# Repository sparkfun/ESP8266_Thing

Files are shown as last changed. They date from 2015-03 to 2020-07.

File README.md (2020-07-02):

SparkFun ESP8266 Thing
========================================

SparkFun ESP8266 Thing (https://www.sparkfun.com/products/13231)

[*SparkFun ESP8266 Thing (WRL-13231)*](https://www.sparkfun.com/products/13231)

The [SparkFun ESP8266 Thing](https://www.sparkfun.com/products/13231) is essentially a breakout and development board for the ESP8266 WiFi SoC. Why the name? We lovingly call it the Thing due to it being the perfect foundation for your Internet of Things. Over the past year, the ESP8266 has been a growing star among IoT or WiFi-related projects. It’s an extremely cost-effective WiFi module, that – with a little extra effort – can be programmed just like any microcontroller. The only unfortunate part is: the ESP8266 has mostly only been available in a tiny, modular form, which, with limited I/O and a “unique” pin-out, can be difficult to build a project around. SparkFun’s new development board for the ESP8266 breaks out all of the module’s pins, and comes equipped with a LiPo charger, power supply, and all of the other supporting circuitry it requires.

The SparkFun ESP8266 Thing is a relatively simple board. The pins are broken out to two parallel, breadboard-compatible rows. USB and LiPo connectors at the top of the board provide power – controlled by the nearby ON/OFF switch. And LEDs towards the inside of the board indicate power, charge, and status of the IC. The ESP8266’s maximum voltage is 3.6V, so the Thing has an onboard 3.3V regulator to deliver a safe, consistent voltage to the IC. That means the ESP8266’s I/O pins also run at 3.3V, you’ll need to level shift any 5V signals running into the IC.

Repository Contents
-------------------

* **/Documentation** - Graphical datasheets (.pdf, .svg)
* **/Hardware** - Eagle design files (.brd, .sch)
* **/Production** - Production panel files (.brd)

Documentation
--------------
* **[Hookup Guide](https://learn.sparkfun.com/tutorials/esp8266-thing-hookup-guide)** - Exhaustive hookup guide for the ESP8266 Thing.
* **[SparkFun Fritzing repo](https://github.com/sparkfun/Fritzing_Parts)** - Fritzing diagrams for SparkFun products.
* **[SparkFun 3D Model repo](https://github.com/sparkfun/3D_Models)** - 3D models of SparkFun products. 

Product Versions
----------------
* [DEV-15258](https://www.sparkfun.com/products/15258)- The Thing in a starter kit.
* [DEV-13231](https://www.sparkfun.com/products/13231)- V1.0 release of the Thing.

License Information
-------------------

This product is _**open source**_! 

Please review the LICENSE.md file for license information. 

If you have any questions or concerns on licensing, please contact technical support on our [SparkFun forums](https://forum.sparkfun.com/viewforum.php?f=152).

Please use, reuse, and modify these files as you see fit. Please maintain attribution to SparkFun Electronics and release anything derivative under the same license.

Distributed as-is; no warranty is given.

- Your friends at SparkFun.

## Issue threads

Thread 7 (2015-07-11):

Arduino package does not co-exists with SparkFun PSoC5 Arduino package

blacktigersoftware, 2015-07-11:
If you have the Sparkfun Arduino PSoC5 package, installing the ESP8266_Thing package makes it disappear.  I did a full reinstall of Arduino 1.6.5, carefully following the PSoC5 steps, quiting Arduino after each step, then performed the ESP8266_Thing installation.
The reason why I make this an issue for ESP8266_Thing is that Visual Micro can still see the PSoC5 package (even though Arduino can't), but has never been able to see the ESP8266_Thing package.

santaimpersonator, 2019-12-30:
We have since handed off the installation of ESP8266 Thing into the board manager... to the [ESP8266 core](https://github.com/esp8266/Arduino). Since, we are no longer are managing this process, I will be closing this issue. If you still have issue installing both packages, please file the issue under the appropriate repository.

Closed 2019-12-30.

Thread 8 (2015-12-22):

On the two jumpered pins, the one labeled DTR is incorrect

jeremyabel, 2015-12-22:
Confirmed in the brd file and the physical board, the left-most pin is labeled DTR, but it should be the rightmost pin which is labele DTR.

bboyho, 2019-03-01:
Hi,

The current boards have the correct silkscreen label. I am not sure when this might have occurred but it looks like it was fixed.

Closed 2019-03-01.

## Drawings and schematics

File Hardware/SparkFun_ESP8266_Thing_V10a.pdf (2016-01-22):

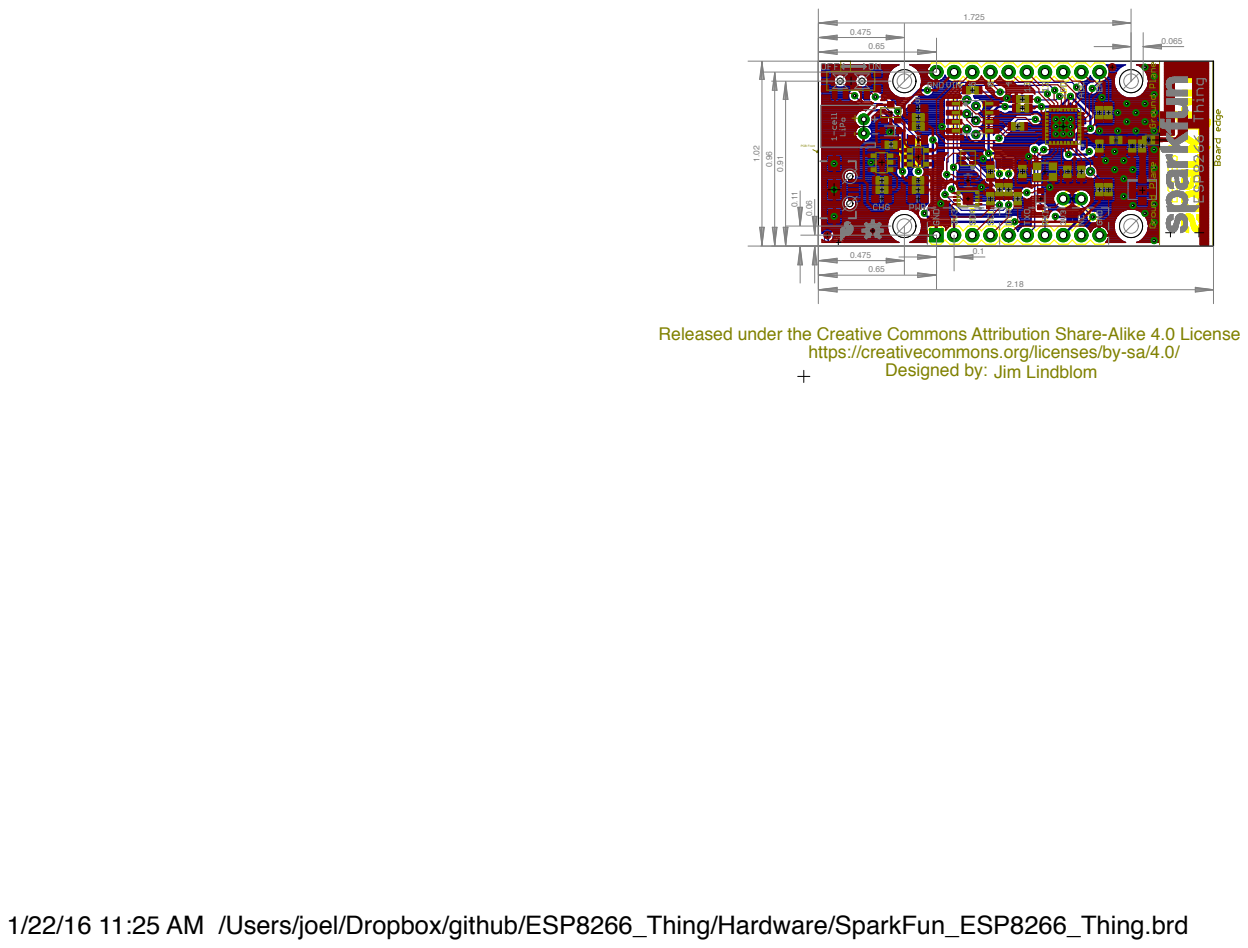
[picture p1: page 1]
Jim Lindblom; Designed by:; PCB Front

Released under the Creative Commons Attribution Share-Alike 4.0 License

https://creativecommons.org/licenses/by-sa/4.0/

1/22/16 11:25 AM /Users/joel/Dropbox/github/ESP8266_Thing/Hardware/SparkFun_ESP8266_Thing.brd

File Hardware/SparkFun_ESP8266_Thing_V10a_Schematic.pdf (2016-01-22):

## VCC Range:

1.7V->3.6V

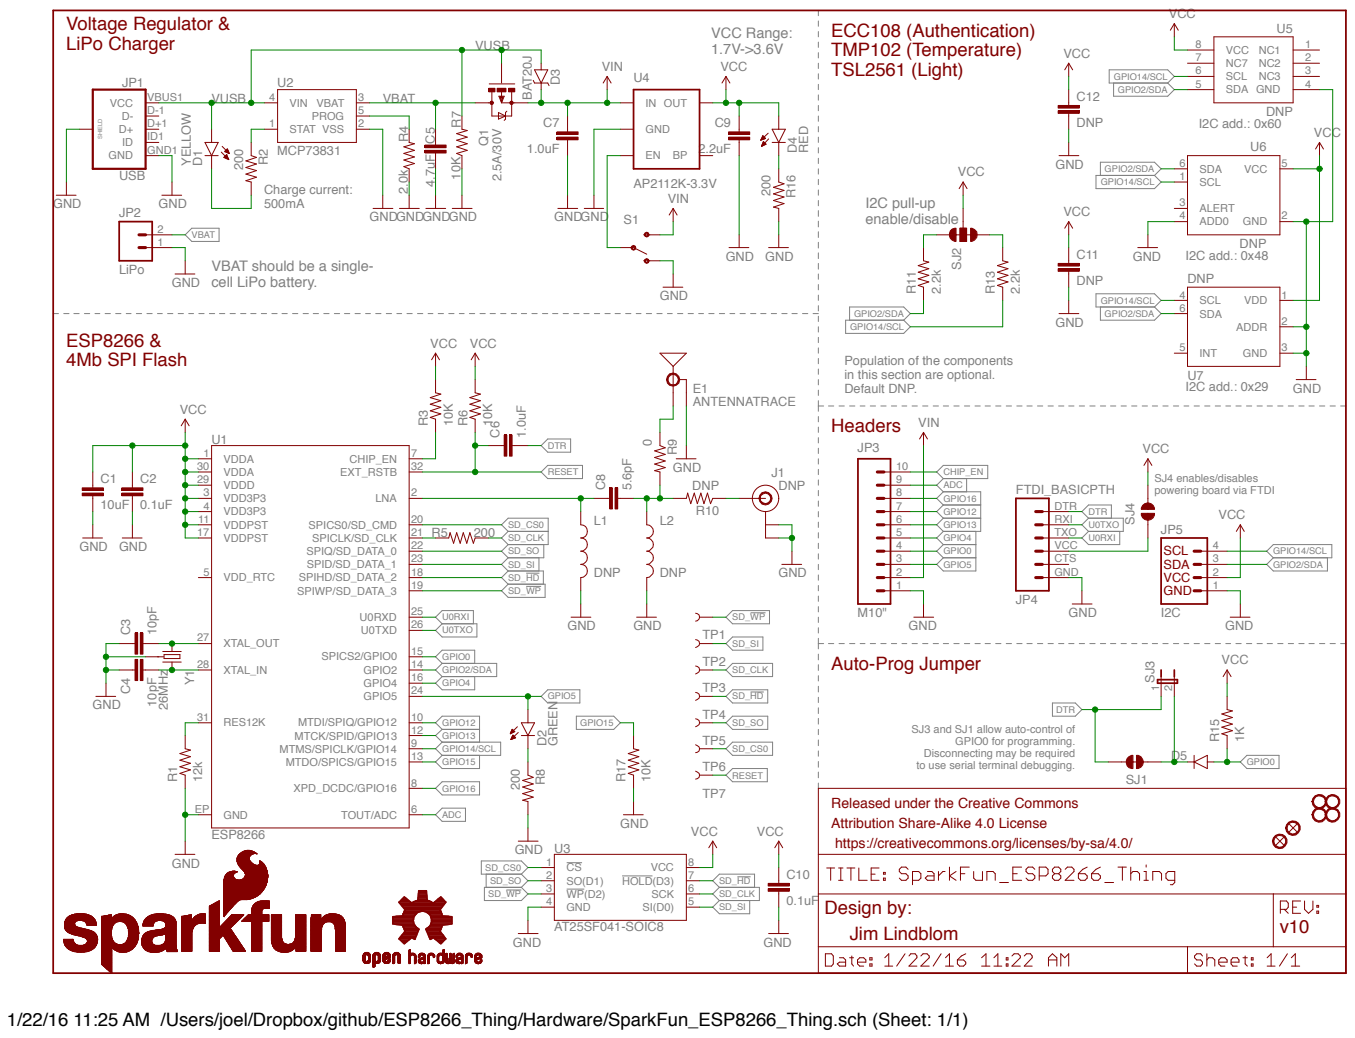
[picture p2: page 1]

VBAT should be a single-
cell LiPo battery.

Population of the components
in this section are optional.
Default DNP.

SJ4 enables/disables
powering board via FTDI

SJ3 and SJ1 allow auto-control of

GPIO0 for programming.
Disconnecting may be required
to use serial terminal debugging.

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

1/22/16 11:25 AM /Users/joel/Dropbox/github/ESP8266_Thing/Hardware/SparkFun_ESP8266_Thing.sch (Sheet: 1/1)

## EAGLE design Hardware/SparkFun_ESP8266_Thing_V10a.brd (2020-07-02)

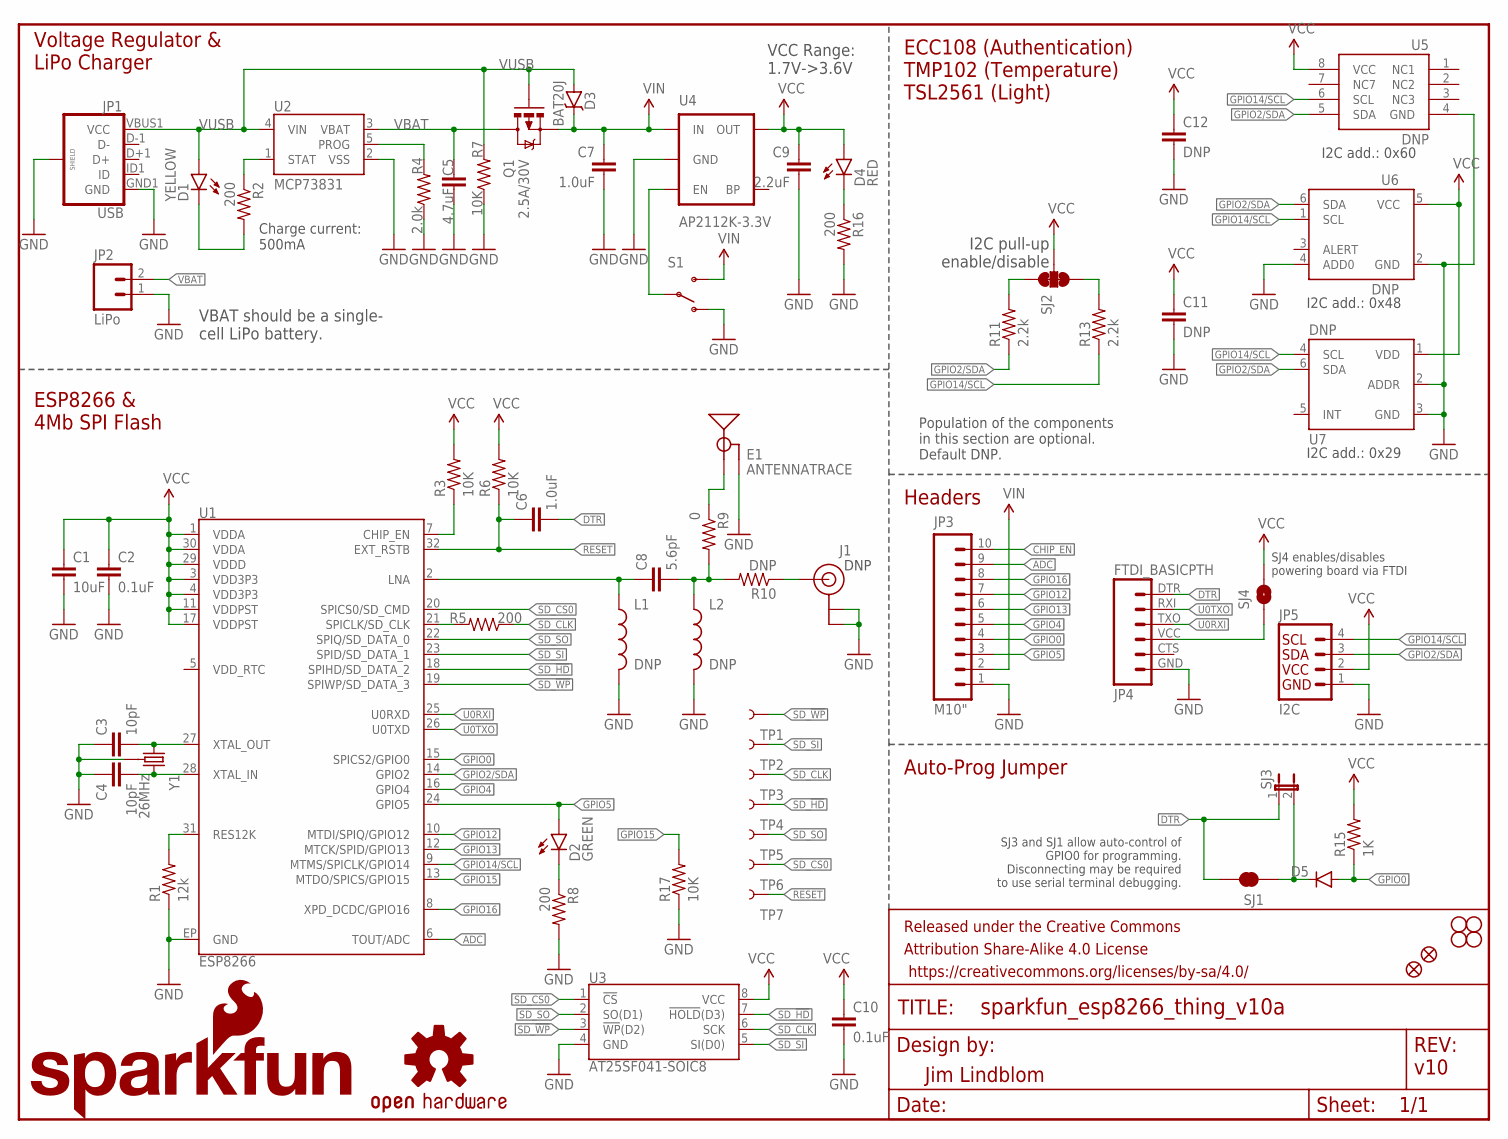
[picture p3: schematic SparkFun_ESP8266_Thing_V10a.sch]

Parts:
C1: 10uF; 0603-CAP
C2, C10: 0.1uF; 0603-CAP
C3, C4: 10pF; 0603-CAP
C5: 4.7uF; 0603-CAP
C6: 1.0uF; 0603-CAP
C7: 1.0uF; 0805
C8: 5.6pF; 0603-CAP
C9: 2.2uF; 0603-CAP
C11, C12: DNP; 0603-CAP
D1: YELLOW; LED-0603
D2: GREEN; LED-0603
D3: BAT20J; SOD-323
D4: RED; LED-0603
D5: DIODEBAS16; SOD-323
E1: ANTENNATRACE; TRACE_ANTENNA_2.4GHZ_25.7MM
FID1, FID2: FIDUCIAL1X2; FIDUCIAL-1X2
FRAME1: FRAME-LETTER; CREATIVE_COMMONS
J1: DNP; U.FL
JP1: USB; USB-B-MICRO-SMD_V03
JP2: LiPo; JST-2-PTH
JP3: M10"; 1X10
JP4: FTDI_BASICPTH; FTDI_BASIC
JP5: I2C; 1X04
L1, L2: DNP; 0603
LOGO1: SFE_LOGO_NAME.2_INCH; SFE_LOGO_NAME_.2
LOGO3: SFE_LOGO_FLAME.1_INCH; SFE_LOGO_FLAME_.1
LOGO4: OSHW-LOGOS; OSHW-LOGO-S
Q1: 2.5A/30V; SOT23-3
R1: 12k; 0603-RES
R2, R5, R8, R16: 200; 0603-RES
R3, R6, R7, R17: 10K; 0603-RES
R4: 2.0k; 0603-RES
R9: 0; 0603
R10: DNP; 0603-RES
R11, R13: 2.2k; 0603-RES
R15: 1K; 0603-RES
S1: SWITCH-SPDT-SMD-A; SWITCH-SPST-SMD-A
SJ1: JUMPER-PAD-2-NC_BY_TRACE; PAD-JUMPER-2-NC_BY_TRACE_YES_SILK
SJ2: JUMPER-PAD-3-NC_BY_TRACE; PAD-JUMPER-3-3OF3_NC_BY_TRACE_YES_SILK_FULL_BOX
SJ3: JUMPER-PTH-2-NC; PTH-JUMPER-NC_BOTTOM_NO_SILK
SJ4: JUMPER-PAD-2-NOYES_SILK; PAD-JUMPER-2-NO_YES_SILK
STANDOFF1, STANDOFF2, STANDOFF3, STANDOFF4: STAND-OFF
TP1, TP2, TP3, TP4, TP5, TP6, TP7: TEST-POINT3X5; PAD.03X.05
U1: ESP8266; QFN32
U2: MCP73831; SOT23-5
U3: AT25SF041-SOIC8; SO08
U4: AP2112K-3.3V; SOT23-5
U5: DNP; UDFN8
U6: DNP; SOT563-2
U7: DNP; FN-6
Y1: 26MHz; CRYSTAL-SMD-3.2X2.5

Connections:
ADC: JP3.9, U1.6 (TOUT/ADC)
ANT: J1.P$3 (SIGNAL), R10.1
CHIP_EN: JP3.10, R3.1, U1.7 (CHIP_EN)
DTR: C6.2, JP4.DTR (1), SJ1.2, SJ3.1
FTDI_VCC: JP4.VCC (4), SJ4.1
GND: C1.2, C2.2, C3.1, C4.1, C5.2, C7.2, C9.2, C10.2, C11.2, C12.2, E1.GND, E1.GND2 (GND), J1.P$1 (GND), J1.P$2 (GND), JP1.GND1 (GND), JP1.SHIELD1 (SHIELD), JP1.SHIELD2 (SHIELD), JP1.SHIELD3 (SHIELD), JP2.1, JP3.1, JP4.GND (6), JP5.1, L1.2, L2.2, R1.1, R4.1, R7.1, R8.2, R16.2, R17.1, S1.1 (O), U1.EP (GND), U2.2 (VSS), U3.4 (GND), U4.2 (GND), U5.4 (GND), U6.2 (GND), U6.4 (ADD0), U7.2 (ADDR), U7.3 (GND), Y1.2 (GND), Y1.4 (GND)
GPIO0: D5.A, JP3.4, R15.1, U1.15 (SPICS2/GPIO0)
GPIO2/SDA: JP5.3, R11.1, U1.14 (GPIO2), U5.5 (SDA), U6.6 (SDA), U7.6 (SDA)
GPIO4: JP3.5, U1.16 (GPIO4)
GPIO5: D2.A, JP3.3, U1.24 (GPIO5)
GPIO12: JP3.7, U1.10 (MTDI/SPIQ/GPIO12)
GPIO13: JP3.6, U1.12 (MTCK/SPID/GPIO13)
GPIO14/SCL: JP5.4, R13.1, U1.9 (MTMS/SPICLK/GPIO14), U5.6 (SCL), U6.1 (SCL), U7.4 (SCL)
GPIO15: R17.2, U1.13 (MTDO/SPICS/GPIO15)
GPIO16: JP3.8, U1.8 (XPD_DCDC/GPIO16)
LNA: C8.1, L1.1, U1.2 (LNA)
unnamed: R1.2, U1.31 (RES12K)
unnamed: C4.2, U1.28 (XTAL_IN), Y1.3 (2)
unnamed: C3.2, U1.27 (XTAL_OUT), Y1.1
unnamed: D4.C, R16.1
unnamed: C8.2, L2.1, R9.2, R10.2
unnamed: R5.2, U1.21 (SPICLK/SD_CLK)
unnamed: D5.C, SJ1.1, SJ3.2
unnamed: R11.2, SJ2.1
unnamed: R13.2, SJ2.3
unnamed: S1.2, U4.3 (EN)
unnamed: R4.2, U2.5 (PROG)
unnamed: D2.C, R8.1
unnamed: D1.C, R2.2
unnamed: R2.1, U2.1 (STAT)
RESET: C6.1, R6.1, TP7.P$1, U1.32 (EXT_RSTB)
SD_!HD!: TP4.P$1, U1.18 (SPIHD/SD_DATA_2), U3.7 (!HOLD!(D3))
SD_!WP!: TP1.P$1, U1.19 (SPIWP/SD_DATA_3), U3.3 (!WP!(D2))
SD_CLK: R5.1, TP3.P$1, U3.6 (SCK)
SD_CS0: TP6.P$1, U1.20 (SPICS0/SD_CMD), U3.1 (!CS!)
SD_SI: TP2.P$1, U1.23 (SPID/SD_DATA_1), U3.5 (SI(D0))
SD_SO: TP5.P$1, U1.22 (SPIQ/SD_DATA_0), U3.2 (SO(D1))
TRACE_ANT: E1.ANT (SIGNAL), R9.1
U0RXI: JP4.TXO (3), U1.25 (U0RXD)
U0TXO: JP4.RXI (2), U1.26 (U0TXD)
VBAT: C5.1, JP2.2, Q1.3 (D), U2.3 (VBAT)
VCC: C1.1, C2.1, C9.1, C10.1, C11.1, C12.1, D4.A, JP5.2, R3.2, R6.2, R15.2, SJ2.2, SJ4.2, U1.1 (VDDA), U1.3 (VDD3P3), U1.4 (VDD3P3), U1.11 (VDDPST), U1.17 (VDDPST), U1.29 (VDDD), U1.30 (VDDA), U3.8 (VCC), U4.5 (OUT), U5.8 (VCC), U6.5 (VCC), U7.1 (VDD)
VIN: C7.1, D3.C, JP3.2, Q1.2 (S), S1.3 (S), U4.1 (IN)
VUSB: D1.A, D3.A, JP1.VBUS1 (VCC), Q1.1 (G), R7.2, U2.4 (VIN)

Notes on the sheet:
Jim Lindblom
ECC108 (Authentication) TMP102 (Temperature) TSL2561 (Light)
Voltage Regulator & LiPo Charger
ESP8266 & 4Mb SPI Flash
Headers
Auto-Prog Jumper
v10
VCC Range: 1.7V->3.6V
VBAT should be a single- cell LiPo battery.
I2C pull-up enable/disable
SJ4 enables/disables powering board via FTDI
SJ3 and SJ1 allow auto-control of GPIO0 for programming. Disconnecting may be required to use serial terminal debugging.
I2C add.: 0x48
I2C add.: 0x60
I2C add.: 0x29
Population of the components in this section are optional. Default DNP.
Charge current: 500mA
DNP

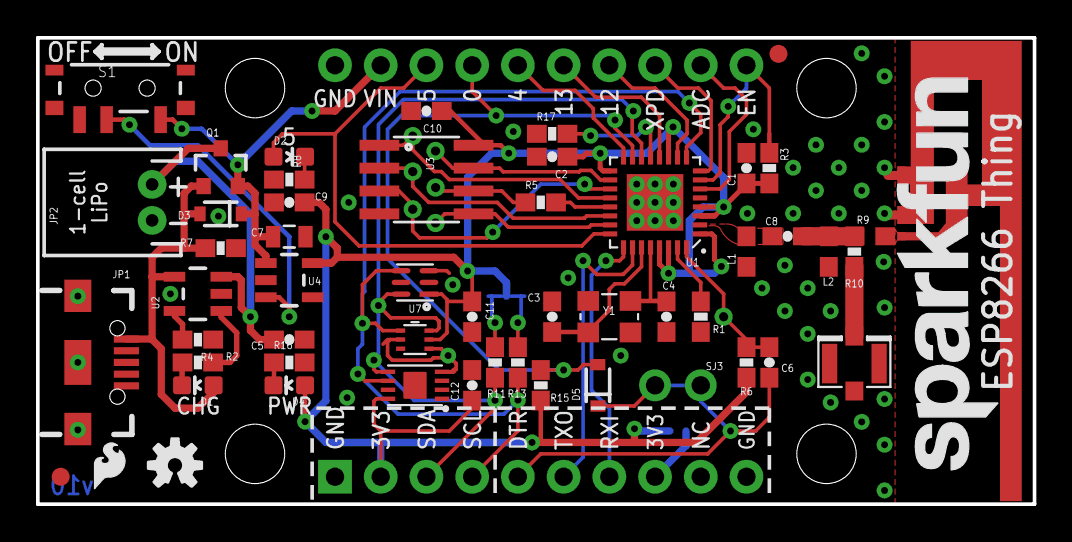
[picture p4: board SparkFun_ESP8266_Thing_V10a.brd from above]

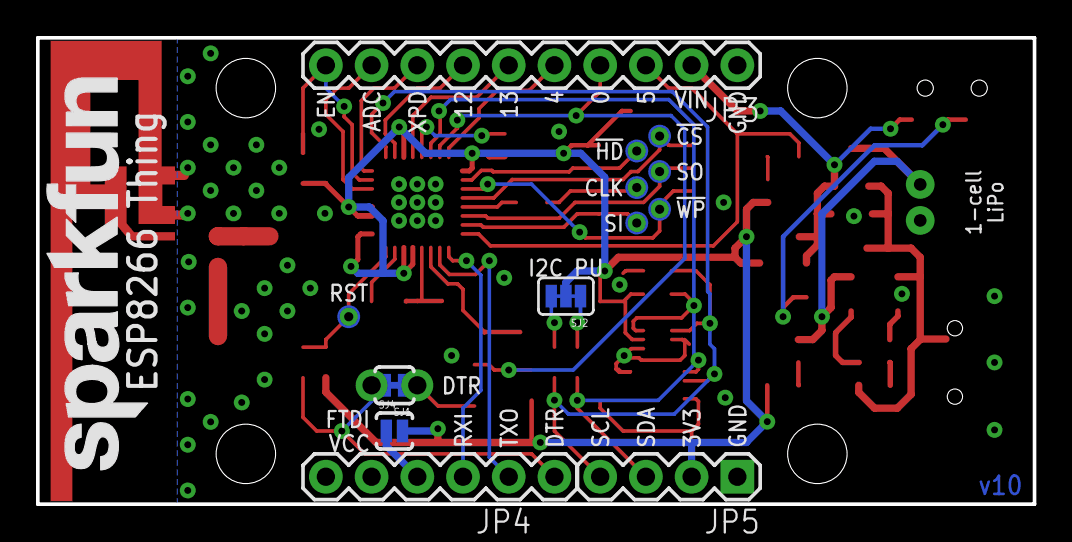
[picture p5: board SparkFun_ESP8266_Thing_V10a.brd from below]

Board: 2 copper layers, 55.4 x 25.9 mm, 73 parts (14 on the bottom side), 44 nets.

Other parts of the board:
LOGO5: SFE_LOGO_NAME.2_INCH; SFE_LOGO_NAME_.2

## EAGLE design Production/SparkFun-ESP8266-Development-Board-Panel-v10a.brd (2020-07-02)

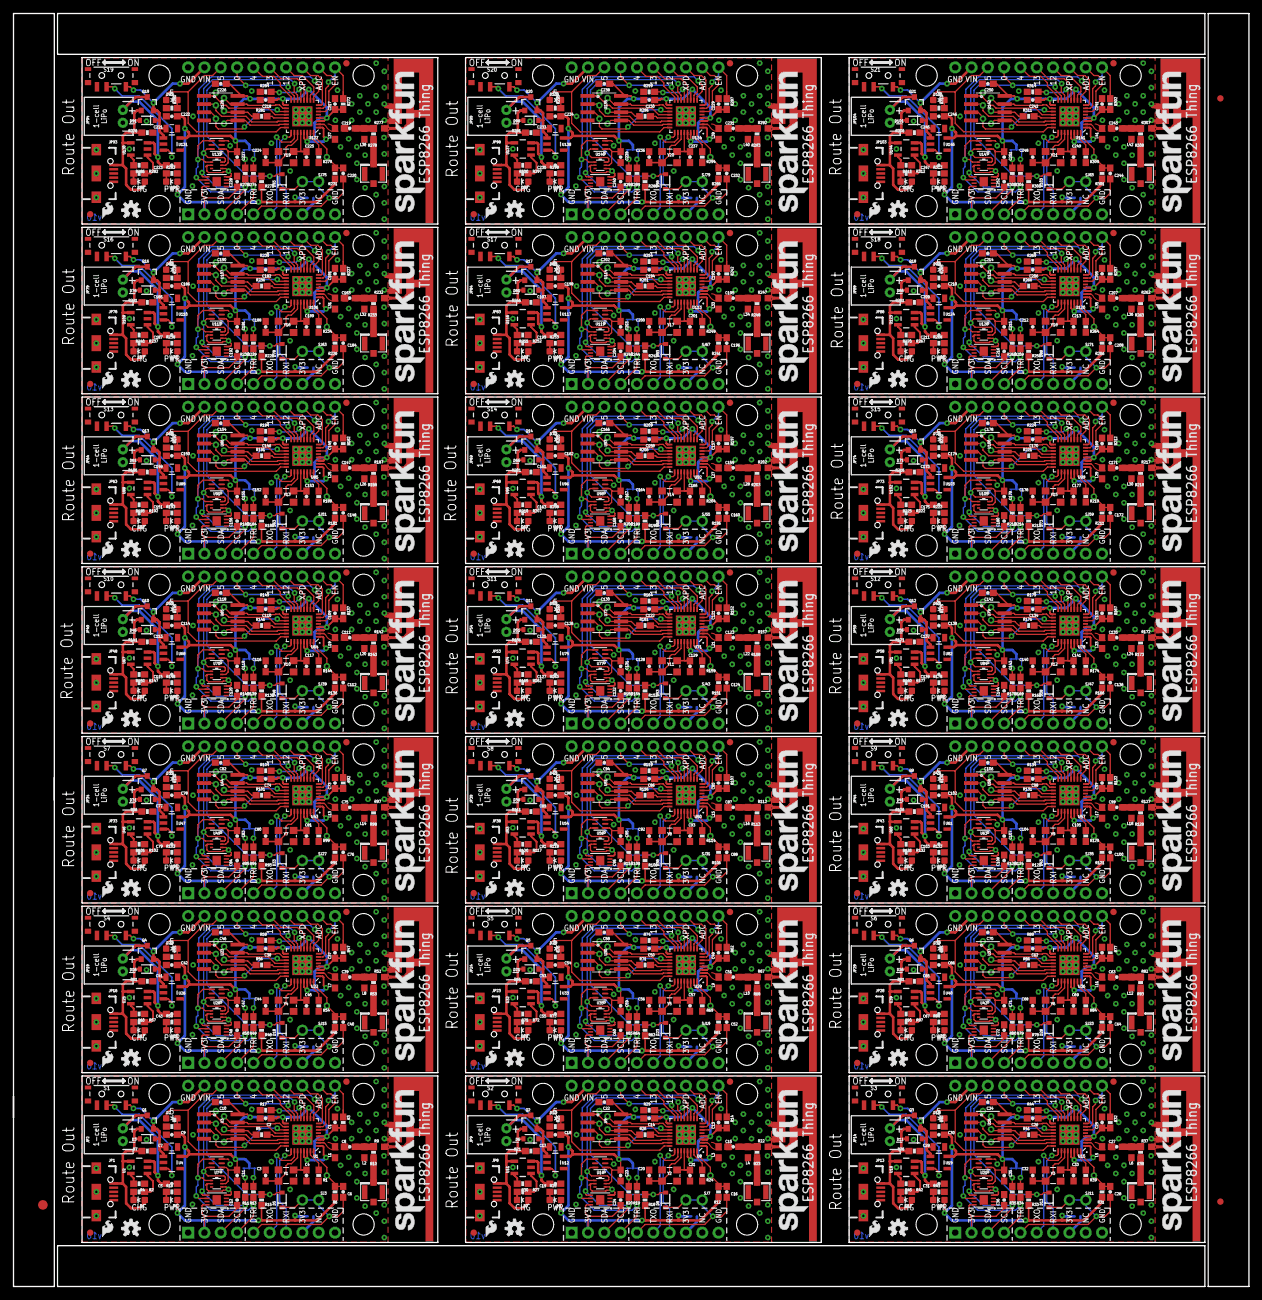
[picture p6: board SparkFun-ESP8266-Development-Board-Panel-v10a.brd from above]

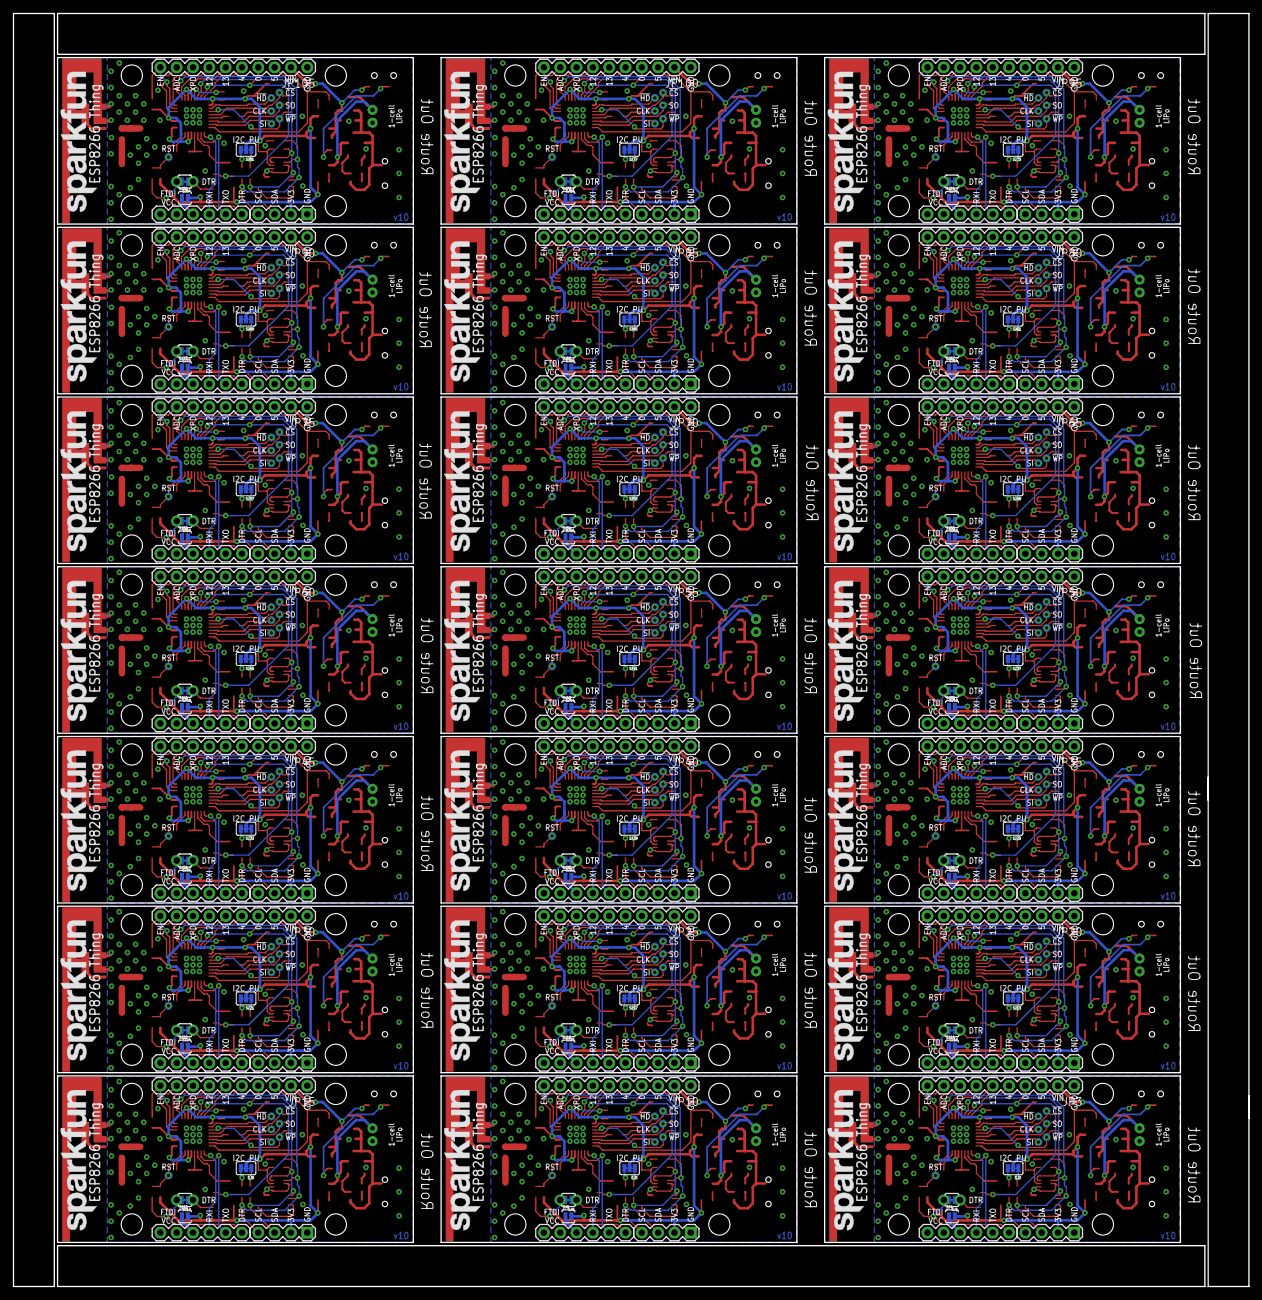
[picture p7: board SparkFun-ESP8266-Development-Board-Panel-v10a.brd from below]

Board: 2 copper layers, 192.3 x 198.1 mm, 1515 parts (294 on the bottom side), 924 nets.

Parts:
C1, C13, C25, C37, C49, C61, C73, C85, C97, C109, C121, C133, C145, C157, C169, C181, C193, C205, C217, C229, C241: 10uF; 0603-CAP
C2, C10, C11, C12, C14, C22, C23, C24, C26, C34, C35, C36, C38, C46, C47, C48, C50, C58, C59, C60, C62, C70, C71, C72, C74, C82, C83, C84, C86, C94, C95, C96, C98, C106, C107, C108, C110, C118, C119, C120, C122, C130, C131, C132, C134, C142, C143, C144, C146, C154, C155, C156, C158, C166, C167, C168, C170, C178, C179, C180, C182, C190, C191, C192, C194, C202, C203, C204, C206, C214, C215, C216, C218, C226, C227, C228, C230, C238, C239, C240, C242, C250, C251, C252: 0.1uF; 0603-CAP
C3, C4, C20, C21, C32, C33, C44, C45, C56, C57, C68, C69, C80, C81, C92, C93, C104, C105, C116, C117, C128, C129, C140, C141, C152, C153, C164, C165, C176, C177, C188, C189, C200, C201, C212, C213, C224, C225, C236, C237, C248, C249: 10pF; 0603-CAP
C5, C19, C31, C43, C55, C67, C79, C91, C103, C115, C127, C139, C151, C163, C175, C187, C199, C211, C223, C235, C247: 4.7uF; 0603-CAP
C6, C16, C28, C40, C52, C64, C76, C88, C100, C112, C124, C136, C148, C160, C172, C184, C196, C208, C220, C232, C244: 1.0uF; 0603-CAP
C7, C17, C29, C41, C53, C65, C77, C89, C101, C113, C125, C137, C149, C161, C173, C185, C197, C209, C221, C233, C245: 1.0uF; 0805
C8, C15, C27, C39, C51, C63, C75, C87, C99, C111, C123, C135, C147, C159, C171, C183, C195, C207, C219, C231, C243: 5.6pF; 0603-CAP
C9, C18, C30, C42, C54, C66, C78, C90, C102, C114, C126, C138, C150, C162, C174, C186, C198, C210, C222, C234, C246: 2.2uF; 0603-CAP
D1, D7, D12, D17, D22, D27, D32, D37, D42, D47, D52, D57, D62, D67, D72, D77, D82, D87, D92, D97, D102: YELLOW; LED-0603
D2, D10, D15, D20, D25, D30, D35, D40, D45, D50, D55, D60, D65, D70, D75, D80, D85, D90, D95, D100, D105: GREEN; LED-0603
D3, D6, D11, D16, D21, D26, D31, D36, D41, D46, D51, D56, D61, D66, D71, D76, D81, D86, D91, D96, D101: BAT20J; SOD-323
D4, D9, D14, D19, D24, D29, D34, D39, D44, D49, D54, D59, D64, D69, D74, D79, D84, D89, D94, D99, D104: RED; LED-0603
D5, D8, D13, D18, D23, D28, D33, D38, D43, D48, D53, D58, D63, D68, D73, D78, D83, D88, D93, D98, D103: SOD-323
E1, E2, E3, E4, E5, E6, E7, E8, E9, E10, E11, E12, E13, E14, E15, E16, E17, E18, E19, E20, E21: ANTENNATRACE; TRACE_ANTENNA_2.4GHZ_25.7MM
E$1: FIDUCIAL-1.5X3
E$5, E$6: FIDUCIAL-1X2
FID1, FID2, FID3, FID4, FID5, FID6, FID7, FID8, FID9, FID10, FID11, FID12, FID13, FID14, FID15, FID16, FID17, FID18, FID19, FID20, FID21, FID22, FID23, FID24, FID25, FID26, FID27, FID28, FID29, FID30, FID31, FID32, FID33, FID34, FID35, FID36, FID37, FID38, FID39, FID40, FID41, FID42: FIDUCIAL1X2; FIDUCIAL-1X2
J1, J2, J3, J4, J5, J6, J7, J8, J9, J10, J11, J12, J13, J14, J15, J16, J17, J18, J19, J20, J21: DNP; U.FL
JP1, JP8, JP13, JP18, JP23, JP28, JP33, JP38, JP43, JP48, JP53, JP58, JP63, JP68, JP73, JP78, JP83, JP88, JP93, JP98, JP103: USB; USB-B-MICRO-SMD_V03
JP2, JP9, JP14, JP19, JP24, JP29, JP34, JP39, JP44, JP49, JP54, JP59, JP64, JP69, JP74, JP79, JP84, JP89, JP94, JP99, JP104: LiPo; JST-2-PTH
JP3, JP10, JP15, JP20, JP25, JP30, JP35, JP40, JP45, JP50, JP55, JP60, JP65, JP70, JP75, JP80, JP85, JP90, JP95, JP100, JP105: M10"; 1X10
JP4, JP6, JP11, JP16, JP21, JP26, JP31, JP36, JP41, JP46, JP51, JP56, JP61, JP66, JP71, JP76, JP81, JP86, JP91, JP96, JP101: FTDI_BASICPTH; FTDI_BASIC
JP5, JP7, JP12, JP17, JP22, JP27, JP32, JP37, JP42, JP47, JP52, JP57, JP62, JP67, JP72, JP77, JP82, JP87, JP92, JP97, JP102: I2C; 1X04
L1, L2, L3, L4, L5, L6, L7, L8, L9, L10, L11, L12, L13, L14, L15, L16, L17, L18, L19, L20, L21, L22, L23, L24, L25, L26, L27, L28, L29, L30, L31, L32, L33, L34, L35, L36, L37, L38, L39, L40, L41, L42: DNP; 0603
LOGO1, LOGO2, LOGO5, LOGO8, LOGO9, LOGO12, LOGO13, LOGO16, LOGO17, LOGO20, LOGO21, LOGO24, LOGO25, LOGO28, LOGO29, LOGO32, LOGO33, LOGO36, LOGO37, LOGO40, LOGO41, LOGO44, LOGO45, LOGO48, LOGO49, LOGO52, LOGO53, LOGO56, LOGO57, LOGO60, LOGO61, LOGO64, LOGO65, LOGO68, LOGO69, LOGO72, LOGO73, LOGO76, LOGO77, LOGO80, LOGO81, LOGO84: SFE_LOGO_NAME.2_INCH; SFE_LOGO_NAME_.2
LOGO3, LOGO6, LOGO10, LOGO14, LOGO18, LOGO22, LOGO26, LOGO30, LOGO34, LOGO38, LOGO42, LOGO46, LOGO50, LOGO54, LOGO58, LOGO62, LOGO66, LOGO70, LOGO74, LOGO78, LOGO82: SFE_LOGO_FLAME.1_INCH; SFE_LOGO_FLAME_.1
LOGO4, LOGO7, LOGO11, LOGO15, LOGO19, LOGO23, LOGO27, LOGO31, LOGO35, LOGO39, LOGO43, LOGO47, LOGO51, LOGO55, LOGO59, LOGO63, LOGO67, LOGO71, LOGO75, LOGO79, LOGO83: OSHW-LOGOS; OSHW-LOGO-S
Q1, Q2, Q3, Q4, Q5, Q6, Q7, Q8, Q9, Q10, Q11, Q12, Q13, Q14, Q15, Q16, Q17, Q18, Q19, Q20, Q21: 2.5A/30V; SOT23-3
R1, R24, R39, R54, R69, R84, R99, R114, R129, R144, R159, R174, R189, R204, R219, R234, R249, R264, R279, R294, R309: 12k; 0603-RES
R2, R5, R8, R16, R25, R26, R27, R28, R40, R41, R42, R43, R55, R56, R57, R58, R70, R71, R72, R73, R85, R86, R87, R88, R100, R101, R102, R103, R115, R116, R117, R118, R130, R131, R132, R133, R145, R146, R147, R148, R160, R161, R162, R163, R175, R176, R177, R178, R190, R191, R192, R193, R205, R206, R207, R208, R220, R221, R222, R223, R235, R236, R237, R238, R250, R251, R252, R253, R265, R266, R267, R268, R280, R281, R282, R283, R295, R296, R297, R298, R310, R311, R312, R313: 200; 0603-RES
R3, R6, R7, R12, R14, R17, R21, R29, R31, R32, R36, R44, R46, R47, R51, R59, R61, R62, R66, R74, R76, R77, R81, R89, R91, R92, R96, R104, R106, R107, R111, R119, R121, R122, R126, R134, R136, R137, R141, R149, R151, R152, R156, R164, R166, R167, R171, R179, R181, R182, R186, R194, R196, R197, R201, R209, R211, R212, R216, R224, R226, R227, R231, R239, R241, R242, R246, R254, R256, R257, R261, R269, R271, R272, R276, R284, R286, R287, R291, R299, R301, R302, R306, R314: 10K; 0603-RES
R4, R30, R45, R60, R75, R90, R105, R120, R135, R150, R165, R180, R195, R210, R225, R240, R255, R270, R285, R300, R315: 2.0k; 0603-RES
R9, R22, R37, R52, R67, R82, R97, R112, R127, R142, R157, R172, R187, R202, R217, R232, R247, R262, R277, R292, R307: 0; 0603
R10, R23, R38, R53, R68, R83, R98, R113, R128, R143, R158, R173, R188, R203, R218, R233, R248, R263, R278, R293, R308: DNP; 0603-RES
R11, R13, R19, R20, R34, R35, R49, R50, R64, R65, R79, R80, R94, R95, R109, R110, R124, R125, R139, R140, R154, R155, R169, R170, R184, R185, R199, R200, R214, R215, R229, R230, R244, R245, R259, R260, R274, R275, R289, R290, R304, R305: 2.2k; 0603-RES
R15, R18, R33, R48, R63, R78, R93, R108, R123, R138, R153, R168, R183, R198, R213, R228, R243, R258, R273, R288, R303: 1K; 0603-RES
S1, S2, S3, S4, S5, S6, S7, S8, S9, S10, S11, S12, S13, S14, S15, S16, S17, S18, S19, S20, S21: SWITCH-SPST-SMD-A
SJ1, SJ8, SJ12, SJ16, SJ20, SJ24, SJ28, SJ32, SJ36, SJ40, SJ44, SJ48, SJ52, SJ56, SJ60, SJ64, SJ68, SJ72, SJ76, SJ80, SJ84: PAD-JUMPER-2-NC_BY_TRACE_YES_SILK
SJ2, SJ5, SJ9, SJ13, SJ17, SJ21, SJ25, SJ29, SJ33, SJ37, SJ41, SJ45, SJ49, SJ53, SJ57, SJ61, SJ65, SJ69, SJ73, SJ77, SJ81: PAD-JUMPER-3-3OF3_NC_BY_TRACE_YES_SILK_FULL_BOX
SJ3, SJ7, SJ11, SJ15, SJ19, SJ23, SJ27, SJ31, SJ35, SJ39, SJ43, SJ47, SJ51, SJ55, SJ59, SJ63, SJ67, SJ71, SJ75, SJ79, SJ83: PTH-JUMPER-NC_BOTTOM_NO_SILK
SJ4, SJ6, SJ10, SJ14, SJ18, SJ22, SJ26, SJ30, SJ34, SJ38, SJ42, SJ46, SJ50, SJ54, SJ58, SJ62, SJ66, SJ70, SJ74, SJ78, SJ82: PAD-JUMPER-2-NO_YES_SILK
STANDOFF1, STANDOFF2, STANDOFF3, STANDOFF4, STANDOFF5, STANDOFF6, STANDOFF7, STANDOFF8, STANDOFF9, STANDOFF10, STANDOFF11, STANDOFF12, STANDOFF13, STANDOFF14, STANDOFF15, STANDOFF16, STANDOFF17, STANDOFF18, STANDOFF19, STANDOFF20, STANDOFF21, STANDOFF22, STANDOFF23, STANDOFF24, STANDOFF25, STANDOFF26, STANDOFF27, STANDOFF28, STANDOFF29, STANDOFF30, STANDOFF31, STANDOFF32, STANDOFF33, STANDOFF34, STANDOFF35, STANDOFF36, STANDOFF37, STANDOFF38, STANDOFF39, STANDOFF40, STANDOFF41, STANDOFF42, STANDOFF43, STANDOFF44, STANDOFF45, STANDOFF46, STANDOFF47, STANDOFF48, STANDOFF49, STANDOFF50, STANDOFF51, STANDOFF52, STANDOFF53, STANDOFF54, STANDOFF55, STANDOFF56, STANDOFF57, STANDOFF58, STANDOFF59, STANDOFF60, STANDOFF61, STANDOFF62, STANDOFF63, STANDOFF64, STANDOFF65, STANDOFF66, STANDOFF67, STANDOFF68, STANDOFF69, STANDOFF70, STANDOFF71, STANDOFF72, STANDOFF73, STANDOFF74, STANDOFF75, STANDOFF76, STANDOFF77, STANDOFF78, STANDOFF79, STANDOFF80, STANDOFF81, STANDOFF82, STANDOFF83, STANDOFF84: STAND-OFF
TP1, TP2, TP3, TP4, TP5, TP6, TP7, TP8, TP9, TP10, TP11, TP12, TP13, TP14, TP15, TP16, TP17, TP18, TP19, TP20, TP21, TP22, TP23, TP24, TP25, TP26, TP27, TP28, TP29, TP30, TP31, TP32, TP33, TP34, TP35, TP36, TP37, TP38, TP39, TP40, TP41, TP42, TP43, TP44, TP45, TP46, TP47, TP48, TP49, TP50, TP51, TP52, TP53, TP54, TP55, TP56, TP57, TP58, TP59, TP60, TP61, TP62, TP63, TP64, TP65, TP66, TP67, TP68, TP69, TP70, TP71, TP72, TP73, TP74, TP75, TP76, TP77, TP78, TP79, TP80, TP81, TP82, TP83, TP84, TP85, TP86, TP87, TP88, TP89, TP90, TP91, TP92, TP93, TP94, TP95, TP96, TP97, TP98, TP99, TP100, TP101, TP102, TP103, TP104, TP105, TP106, TP107, TP108, TP109, TP110, TP111, TP112, TP113, TP114, TP115, TP116, TP117, TP118, TP119, TP120, TP121, TP122, TP123, TP124, TP125, TP126, TP127, TP128, TP129, TP130, TP131, TP132, TP133, TP134, TP135, TP136, TP137, TP138, TP139, TP140, TP141, TP142, TP143, TP144, TP145, TP146, TP147: PAD.03X.05
U1, U8, U15, U22, U29, U36, U43, U50, U57, U64, U71, U78, U85, U92, U99, U106, U113, U120, U127, U134, U141: ESP8266; QFN32
U2, U11, U18, U25, U32, U39, U46, U53, U60, U67, U74, U81, U88, U95, U102, U109, U116, U123, U130, U137, U144: MCP73831; SOT23-5
U3, U9, U16, U23, U30, U37, U44, U51, U58, U65, U72, U79, U86, U93, U100, U107, U114, U121, U128, U135, U142: AT25SF041-SOIC8; SO08
U4, U12, U19, U26, U33, U40, U47, U54, U61, U68, U75, U82, U89, U96, U103, U110, U117, U124, U131, U138, U145: AP2112K-3.3V; SOT23-5
U5, U10, U17, U24, U31, U38, U45, U52, U59, U66, U73, U80, U87, U94, U101, U108, U115, U122, U129, U136, U143: ATECC108-MAHDA; UDFN8
U6, U13, U20, U27, U34, U41, U48, U55, U62, U69, U76, U83, U90, U97, U104, U111, U118, U125, U132, U139, U146: TMP1021:1; SOT563-2
U7, U14, U21, U28, U35, U42, U49, U56, U63, U70, U77, U84, U91, U98, U105, U112, U119, U126, U133, U140, U147: TSL2561FN; FN-6
Y1, Y2, Y3, Y4, Y5, Y6, Y7, Y8, Y9, Y10, Y11, Y12, Y13, Y14, Y15, Y16, Y17, Y18, Y19, Y20, Y21: 26MHz; CRYSTAL-SMD-3.2X2.5

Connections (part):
ADC: JP3.9, U1.6
ADC1: JP10.9, U8.6
ADC2: JP15.9, U15.6
ADC3: JP20.9, U22.6
ADC4: JP25.9, U29.6
ADC5: JP30.9, U36.6
ADC6: JP35.9, U43.6
ADC7: JP40.9, U50.6
ADC8: JP45.9, U57.6
ADC9: JP50.9, U64.6
ADC10: JP55.9, U71.6
ADC11: JP60.9, U78.6
ADC12: JP65.9, U85.6
ADC13: JP70.9, U92.6
ADC14: JP75.9, U99.6
ADC15: JP80.9, U106.6
ADC16: JP85.9, U113.6
ADC17: JP90.9, U120.6
ADC18: JP95.9, U127.6
ADC19: JP100.9, U134.6
ADC20: JP105.9, U141.6
ANT: J1.P$3, R10.1
ANT1: J2.P$3, R23.1
ANT2: J3.P$3, R38.1
ANT3: J4.P$3, R53.1
ANT4: J5.P$3, R68.1
ANT5: J6.P$3, R83.1
ANT6: J7.P$3, R98.1
ANT7: J8.P$3, R113.1
ANT8: J9.P$3, R128.1
ANT9: J10.P$3, R143.1
ANT10: J11.P$3, R158.1
ANT11: J12.P$3, R173.1
ANT12: J13.P$3, R188.1
ANT13: J14.P$3, R203.1
ANT14: J15.P$3, R218.1
ANT15: J16.P$3, R233.1
ANT16: J17.P$3, R248.1
ANT17: J18.P$3, R263.1
ANT18: J19.P$3, R278.1
ANT19: J20.P$3, R293.1
ANT20: J21.P$3, R308.1
CHIP_EN: JP3.10, R3.1, U1.7
CHIP_EN1: JP10.10, R14.1, U8.7
CHIP_EN2: JP15.10, R32.1, U15.7
CHIP_EN3: JP20.10, R47.1, U22.7
CHIP_EN4: JP25.10, R62.1, U29.7
CHIP_EN5: JP30.10, R77.1, U36.7
CHIP_EN6: JP35.10, R92.1, U43.7
CHIP_EN7: JP40.10, R107.1, U50.7
CHIP_EN8: JP45.10, R122.1, U57.7
CHIP_EN9: JP50.10, R137.1, U64.7
CHIP_EN10: JP55.10, R152.1, U71.7
CHIP_EN11: JP60.10, R167.1, U78.7
CHIP_EN12: JP65.10, R182.1, U85.7
CHIP_EN13: JP70.10, R197.1, U92.7
CHIP_EN14: JP75.10, R212.1, U99.7
CHIP_EN15: JP80.10, R227.1, U106.7
CHIP_EN16: JP85.10, R242.1, U113.7
CHIP_EN17: JP90.10, R257.1, U120.7
CHIP_EN18: JP95.10, R272.1, U127.7
CHIP_EN19: JP100.10, R287.1, U134.7
CHIP_EN20: JP105.10, R302.1, U141.7
DTR: C6.2, JP4.DTR, SJ1.2, SJ3.1
DTR1: C16.2, JP6.DTR, SJ7.1, SJ8.2
DTR2: C28.2, JP11.DTR, SJ11.1, SJ12.2
DTR3: C40.2, JP16.DTR, SJ15.1, SJ16.2
DTR4: C52.2, JP21.DTR, SJ19.1, SJ20.2
DTR5: C64.2, JP26.DTR, SJ23.1, SJ24.2
DTR6: C76.2, JP31.DTR, SJ27.1, SJ28.2
DTR7: C88.2, JP36.DTR, SJ31.1, SJ32.2
DTR8: C100.2, JP41.DTR, SJ35.1, SJ36.2
DTR9: C112.2, JP46.DTR, SJ39.1, SJ40.2
DTR10: C124.2, JP51.DTR, SJ43.1, SJ44.2
DTR11: C136.2, JP56.DTR, SJ47.1, SJ48.2
DTR12: C148.2, JP61.DTR, SJ51.1, SJ52.2
DTR13: C160.2, JP66.DTR, SJ55.1, SJ56.2
DTR14: C172.2, JP71.DTR, SJ59.1, SJ60.2
DTR15: C184.2, JP76.DTR, SJ63.1, SJ64.2
DTR16: C196.2, JP81.DTR, SJ67.1, SJ68.2
DTR17: C208.2, JP86.DTR, SJ71.1, SJ72.2
DTR18: C220.2, JP91.DTR, SJ75.1, SJ76.2
DTR19: C232.2, JP96.DTR, SJ79.1, SJ80.2
DTR20: C244.2, JP101.DTR, SJ83.1, SJ84.2
FTDI_VCC: JP4.VCC, SJ4.1
FTDI_VCC1: JP6.VCC, SJ6.1
FTDI_VCC2: JP11.VCC, SJ10.1
FTDI_VCC3: JP16.VCC, SJ14.1
FTDI_VCC4: JP21.VCC, SJ18.1
FTDI_VCC5: JP26.VCC, SJ22.1
FTDI_VCC6: JP31.VCC, SJ26.1
FTDI_VCC7: JP36.VCC, SJ30.1
FTDI_VCC8: JP41.VCC, SJ34.1
FTDI_VCC9: JP46.VCC, SJ38.1
FTDI_VCC10: JP51.VCC, SJ42.1
FTDI_VCC11: JP56.VCC, SJ46.1
FTDI_VCC12: JP61.VCC, SJ50.1
FTDI_VCC13: JP66.VCC, SJ54.1
FTDI_VCC14: JP71.VCC, SJ58.1
FTDI_VCC15: JP76.VCC, SJ62.1
FTDI_VCC16: JP81.VCC, SJ66.1
FTDI_VCC17: JP86.VCC, SJ70.1
FTDI_VCC18: JP91.VCC, SJ74.1
FTDI_VCC19: JP96.VCC, SJ78.1
FTDI_VCC20: JP101.VCC, SJ82.1
GND: C1.2, C2.2, C3.1, C4.1, C5.2, C7.2, C9.2, C10.2, C11.2, C12.2, E1.GND, E1.GND2, J1.P$1, J1.P$2, JP1.GND1, JP1.SHIELD1, JP1.SHIELD2, JP1.SHIELD3, JP2.1, JP3.1, JP4.GND, JP5.1, L1.2, L2.2, R1.1, R4.1, R7.1, R8.2, R16.2, R17.1, S1.1, U1.EP, U2.2, U3.4, U4.2, U5.4, U6.2, U6.4, U7.2, U7.3, Y1.2, Y1.4
GND1: C13.2, C14.2, C17.2, C18.2, C19.2, C20.1, C21.1, C22.2, C23.2, C24.2, E2.GND, E2.GND2, J2.P$1, J2.P$2, JP6.GND, JP7.1, JP8.GND1, JP8.SHIELD1, JP8.SHIELD2, JP8.SHIELD3, JP9.1, JP10.1, L3.2, L4.2, R21.1, R24.1, R25.2, R28.2, R29.1, R30.1, S2.1, U8.EP, U9.4, U10.4, U11.2, U12.2, U13.2, U13.4, U14.2, U14.3, Y2.2, Y2.4
GND2: C25.2, C26.2, C29.2, C30.2, C31.2, C32.1, C33.1, C34.2, C35.2, C36.2, E3.GND, E3.GND2, J3.P$1, J3.P$2, JP11.GND, JP12.1, JP13.GND1, JP13.SHIELD1, JP13.SHIELD2, JP13.SHIELD3, JP14.1, JP15.1, L5.2, L6.2, R36.1, R39.1, R40.2, R43.2, R44.1, R45.1, S3.1, U15.EP, U16.4, U17.4, U18.2, U19.2, U20.2, U20.4, U21.2, U21.3, Y3.2, Y3.4
GND3: C37.2, C38.2, C41.2, C42.2, C43.2, C44.1, C45.1, C46.2, C47.2, C48.2, E4.GND, E4.GND2, J4.P$1, J4.P$2, JP16.GND, JP17.1, JP18.GND1, JP18.SHIELD1, JP18.SHIELD2, JP18.SHIELD3, JP19.1, JP20.1, L7.2, L8.2, R51.1, R54.1, R55.2, R58.2, R59.1, R60.1, S4.1, U22.EP, U23.4, U24.4, U25.2, U26.2, U27.2, U27.4, U28.2, U28.3, Y4.2, Y4.4
GND4: C49.2, C50.2, C53.2, C54.2, C55.2, C56.1, C57.1, C58.2, C59.2, C60.2, E5.GND, E5.GND2, J5.P$1, J5.P$2, JP21.GND, JP22.1, JP23.GND1, JP23.SHIELD1, JP23.SHIELD2, JP23.SHIELD3, JP24.1, JP25.1, L9.2, L10.2, R66.1, R69.1, R70.2, R73.2, R74.1, R75.1, S5.1, U29.EP, U30.4, U31.4, U32.2, U33.2, U34.2, U34.4, U35.2, U35.3, Y5.2, Y5.4
GND5: C61.2, C62.2, C65.2, C66.2, C67.2, C68.1, C69.1, C70.2, C71.2, C72.2, E6.GND, E6.GND2, J6.P$1, J6.P$2, JP26.GND, JP27.1, JP28.GND1, JP28.SHIELD1, JP28.SHIELD2, JP28.SHIELD3, JP29.1, JP30.1, L11.2, L12.2, R81.1, R84.1, R85.2, R88.2, R89.1, R90.1, S6.1, U36.EP, U37.4, U38.4, U39.2, U40.2, U41.2, U41.4, U42.2, U42.3, Y6.2, Y6.4
GND6: C73.2, C74.2, C77.2, C78.2, C79.2, C80.1, C81.1, C82.2, C83.2, C84.2, E7.GND, E7.GND2, J7.P$1, J7.P$2, JP31.GND, JP32.1, JP33.GND1, JP33.SHIELD1, JP33.SHIELD2, JP33.SHIELD3, JP34.1, JP35.1, L13.2, L14.2, R96.1, R99.1, R100.2, R103.2, R104.1, R105.1, S7.1, U43.EP, U44.4, U45.4, U46.2, U47.2, U48.2, U48.4, U49.2, U49.3, Y7.2, Y7.4
GND7: C85.2, C86.2, C89.2, C90.2, C91.2, C92.1, C93.1, C94.2, C95.2, C96.2, E8.GND, E8.GND2, J8.P$1, J8.P$2, JP36.GND, JP37.1, JP38.GND1, JP38.SHIELD1, JP38.SHIELD2, JP38.SHIELD3, JP39.1, JP40.1, L15.2, L16.2, R111.1, R114.1, R115.2, R118.2, R119.1, R120.1, S8.1, U50.EP, U51.4, U52.4, U53.2, U54.2, U55.2, U55.4, U56.2, U56.3, Y8.2, Y8.4
GND8: C97.2, C98.2, C101.2, C102.2, C103.2, C104.1, C105.1, C106.2, C107.2, C108.2, E9.GND, E9.GND2, J9.P$1, J9.P$2, JP41.GND, JP42.1, JP43.GND1, JP43.SHIELD1, JP43.SHIELD2, JP43.SHIELD3, JP44.1, JP45.1, L17.2, L18.2, R126.1, R129.1, R130.2, R133.2, R134.1, R135.1, S9.1, U57.EP, U58.4, U59.4, U60.2, U61.2, U62.2, U62.4, U63.2, U63.3, Y9.2, Y9.4
GND9: C109.2, C110.2, C113.2, C114.2, C115.2, C116.1, C117.1, C118.2, C119.2, C120.2, E10.GND, E10.GND2, J10.P$1, J10.P$2, JP46.GND, JP47.1, JP48.GND1, JP48.SHIELD1, JP48.SHIELD2, JP48.SHIELD3, JP49.1, JP50.1, L19.2, L20.2, R141.1, R144.1, R145.2, R148.2, R149.1, R150.1, S10.1, U64.EP, U65.4, U66.4, U67.2, U68.2, U69.2, U69.4, U70.2, U70.3, Y10.2, Y10.4
GND10: C121.2, C122.2, C125.2, C126.2, C127.2, C128.1, C129.1, C130.2, C131.2, C132.2, E11.GND, E11.GND2, J11.P$1, J11.P$2, JP51.GND, JP52.1, JP53.GND1, JP53.SHIELD1, JP53.SHIELD2, JP53.SHIELD3, JP54.1, JP55.1, L21.2, L22.2, R156.1, R159.1, R160.2, R163.2, R164.1, R165.1, S11.1, U71.EP, U72.4, U73.4, U74.2, U75.2, U76.2, U76.4, U77.2, U77.3, Y11.2, Y11.4
GND11: C133.2, C134.2, C137.2, C138.2, C139.2, C140.1, C141.1, C142.2, C143.2, C144.2, E12.GND, E12.GND2, J12.P$1, J12.P$2, JP56.GND, JP57.1, JP58.GND1, JP58.SHIELD1, JP58.SHIELD2, JP58.SHIELD3, JP59.1, JP60.1, L23.2, L24.2, R171.1, R174.1, R175.2, R178.2, R179.1, R180.1, S12.1, U78.EP, U79.4, U80.4, U81.2, U82.2, U83.2, U83.4, U84.2, U84.3, Y12.2, Y12.4
GND12: C145.2, C146.2, C149.2, C150.2, C151.2, C152.1, C153.1, C154.2, C155.2, C156.2, E13.GND, E13.GND2, J13.P$1, J13.P$2, JP61.GND, JP62.1, JP63.GND1, JP63.SHIELD1, JP63.SHIELD2, JP63.SHIELD3, JP64.1, JP65.1, L25.2, L26.2, R186.1, R189.1, R190.2, R193.2, R194.1, R195.1, S13.1, U85.EP, U86.4, U87.4, U88.2, U89.2, U90.2, U90.4, U91.2, U91.3, Y13.2, Y13.4
GND13: C157.2, C158.2, C161.2, C162.2, C163.2, C164.1, C165.1, C166.2, C167.2, C168.2, E14.GND, E14.GND2, J14.P$1, J14.P$2, JP66.GND, JP67.1, JP68.GND1, JP68.SHIELD1, JP68.SHIELD2, JP68.SHIELD3, JP69.1, JP70.1, L27.2, L28.2, R201.1, R204.1, R205.2, R208.2, R209.1, R210.1, S14.1, U92.EP, U93.4, U94.4, U95.2, U96.2, U97.2, U97.4, U98.2, U98.3, Y14.2, Y14.4
GND14: C169.2, C170.2, C173.2, C174.2, C175.2, C176.1, C177.1, C178.2, C179.2, C180.2, E15.GND, E15.GND2, J15.P$1, J15.P$2, JP71.GND, JP72.1, JP73.GND1, JP73.SHIELD1, JP73.SHIELD2, JP73.SHIELD3, JP74.1, JP75.1, L29.2, L30.2, R216.1, R219.1, R220.2, R223.2, R224.1, R225.1, S15.1, U99.EP, U100.4, U101.4, U102.2, U103.2, U104.2, U104.4, U105.2, U105.3, Y15.2, Y15.4
GND15: C181.2, C182.2, C185.2, C186.2, C187.2, C188.1, C189.1, C190.2, C191.2, C192.2, E16.GND, E16.GND2, J16.P$1, J16.P$2, JP76.GND, JP77.1, JP78.GND1, JP78.SHIELD1, JP78.SHIELD2, JP78.SHIELD3, JP79.1, JP80.1, L31.2, L32.2, R231.1, R234.1, R235.2, R238.2, R239.1, R240.1, S16.1, U106.EP, U107.4, U108.4, U109.2, U110.2, U111.2, U111.4, U112.2, U112.3, Y16.2, Y16.4
GND16: C193.2, C194.2, C197.2, C198.2, C199.2, C200.1, C201.1, C202.2, C203.2, C204.2, E17.GND, E17.GND2, J17.P$1, J17.P$2, JP81.GND, JP82.1, JP83.GND1, JP83.SHIELD1, JP83.SHIELD2, JP83.SHIELD3, JP84.1, JP85.1, L33.2, L34.2, R246.1, R249.1, R250.2, R253.2, R254.1, R255.1, S17.1, U113.EP, U114.4, U115.4, U116.2, U117.2, U118.2, U118.4, U119.2, U119.3, Y17.2, Y17.4
GND17: C205.2, C206.2, C209.2, C210.2, C211.2, C212.1, C213.1, C214.2, C215.2, C216.2, E18.GND, E18.GND2, J18.P$1, J18.P$2, JP86.GND, JP87.1, JP88.GND1, JP88.SHIELD1, JP88.SHIELD2, JP88.SHIELD3, JP89.1, JP90.1, L35.2, L36.2, R261.1, R264.1, R265.2, R268.2, R269.1, R270.1, S18.1, U120.EP, U121.4, U122.4, U123.2, U124.2, U125.2, U125.4, U126.2, U126.3, Y18.2, Y18.4
GND18: C217.2, C218.2, C221.2, C222.2, C223.2, C224.1, C225.1, C226.2, C227.2, C228.2, E19.GND, E19.GND2, J19.P$1, J19.P$2, JP91.GND, JP92.1, JP93.GND1, JP93.SHIELD1, JP93.SHIELD2, JP93.SHIELD3, JP94.1, JP95.1, L37.2, L38.2, R276.1, R279.1, R280.2, R283.2, R284.1, R285.1, S19.1, U127.EP, U128.4, U129.4, U130.2, U131.2, U132.2, U132.4, U133.2, U133.3, Y19.2, Y19.4
GND19: C229.2, C230.2, C233.2, C234.2, C235.2, C236.1, C237.1, C238.2, C239.2, C240.2, E20.GND, E20.GND2, J20.P$1, J20.P$2, JP96.GND, JP97.1, JP98.GND1, JP98.SHIELD1, JP98.SHIELD2, JP98.SHIELD3, JP99.1, JP100.1, L39.2, L40.2, R291.1, R294.1, R295.2, R298.2, R299.1, R300.1, S20.1, U134.EP, U135.4, U136.4, U137.2, U138.2, U139.2, U139.4, U140.2, U140.3, Y20.2, Y20.4
GND20: C241.2, C242.2, C245.2, C246.2, C247.2, C248.1, C249.1, C250.2, C251.2, C252.2, E21.GND, E21.GND2, J21.P$1, J21.P$2, JP101.GND, JP102.1, JP103.GND1, JP103.SHIELD1, JP103.SHIELD2, JP103.SHIELD3, JP104.1, JP105.1, L41.2, L42.2, R306.1, R309.1, R310.2, R313.2, R314.1, R315.1, S21.1, U141.EP, U142.4, U143.4, U144.2, U145.2, U146.2, U146.4, U147.2, U147.3, Y21.2, Y21.4
GPIO0: D5.A, JP3.4, R15.1, U1.15
GPIO1: D8.A, JP10.4, R18.1, U8.15
GPIO2: D10.A, JP10.3, U8.24
GPIO2/SDA: JP5.3, R11.1, U1.14, U5.5, U6.6, U7.6
GPIO2/SDA1: JP7.3, R20.1, U8.14, U10.5, U13.6, U14.6
GPIO2/SDA2: JP12.3, R35.1, U15.14, U17.5, U20.6, U21.6
GPIO2/SDA3: JP17.3, R50.1, U22.14, U24.5, U27.6, U28.6
GPIO2/SDA4: JP22.3, R65.1, U29.14, U31.5, U34.6, U35.6
GPIO2/SDA5: JP27.3, R80.1, U36.14, U38.5, U41.6, U42.6
GPIO2/SDA6: JP32.3, R95.1, U43.14, U45.5, U48.6, U49.6
GPIO2/SDA7: JP37.3, R110.1, U50.14, U52.5, U55.6, U56.6
GPIO2/SDA8: JP42.3, R125.1, U57.14, U59.5, U62.6, U63.6
GPIO2/SDA9: JP47.3, R140.1, U64.14, U66.5, U69.6, U70.6
GPIO2/SDA10: JP52.3, R155.1, U71.14, U73.5, U76.6, U77.6
GPIO2/SDA11: JP57.3, R170.1, U78.14, U80.5, U83.6, U84.6
GPIO2/SDA12: JP62.3, R185.1, U85.14, U87.5, U90.6, U91.6
GPIO2/SDA13: JP67.3, R200.1, U92.14, U94.5, U97.6, U98.6
GPIO2/SDA14: JP72.3, R215.1, U99.14, U101.5, U104.6, U105.6
GPIO2/SDA15: JP77.3, R230.1, U106.14, U108.5, U111.6, U112.6
GPIO2/SDA16: JP82.3, R245.1, U113.14, U115.5, U118.6, U119.6
GPIO2/SDA17: JP87.3, R260.1, U120.14, U122.5, U125.6, U126.6
GPIO2/SDA18: JP92.3, R275.1, U127.14, U129.5, U132.6, U133.6
GPIO2/SDA19: JP97.3, R290.1, U134.14, U136.5, U139.6, U140.6
GPIO2/SDA20: JP102.3, R305.1, U141.14, U143.5, U146.6, U147.6
GPIO3: JP10.5, U8.16
GPIO4: JP3.5, U1.16
GPIO5: D2.A, JP3.3, U1.24
GPIO6: JP10.8, U8.8
GPIO7: R29.2, U8.13
GPIO8: JP10.6, U8.12
GPIO9: JP10.7, U8.10
GPIO10: D13.A, JP15.4, R33.1, U15.15
GPIO11: D15.A, JP15.3, U15.24
GPIO12: JP3.7, U1.10
GPIO13: JP3.6, U1.12
GPIO14: JP15.5, U15.16
GPIO14/SCL: JP5.4, R13.1, U1.9, U5.6, U6.1, U7.4
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

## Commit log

2014-11-19 Initial hardware commit
    [PCB checklist_V_1.0.csv, PCB checklist_V_1.0.ods, SparkFun-ESP8266-Development-Board.brd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]
2014-11-19 Adding temporary library. Includes trace antenna(s) and ATECC108.
2014-11-20 Straightening out some nets coming out of ESP8266. Value JP5. Flag label on RESET.
    [SparkFun-ESP8266-Development-Board.brd, SparkFun-ESP8266-Development-Board.sch]
2014-11-20 Adding power LED. Re-arranging power circuitry. Breaking out pin 5.
    [SparkFun-ESP8266-Development-Board.brd, SparkFun-ESP8266-Development-Board.sch]
2014-11-20 Fixing net names for flash signals. Updating bottom silk labels
    [SparkFun-ESP8266-Development-Board.brd, SparkFun-ESP8266-Development-Board.sch]
2015-01-18 Adding pull-down resistor to GPIO15 (required to upload). Not broken out any more.
    [SparkFun-ESP8266-Development-Board.brd, SparkFun-ESP8266-Development-Board.sch]
2015-01-19 Re-arranging 10-pin header pin-out.
    [SparkFun-ESP8266-Development-Board.brd, SparkFun-ESP8266-Development-Board.sch]
2015-01-21 Adding light and temperature sensors. Adding ON/OFF switch. Simplifying DTR-GPIO0 circuit.
    [SparkFun-ESP8266-Development-Board.brd, SparkFun-ESP8266-Development-Board.sch]
2015-01-21 Swapping colors of PWR and pin 5 LEDs. Adding SMD jumper to GPIO0/DTR.
    [SparkFun-ESP8266-Development-Board.brd, SparkFun-ESP8266-Development-Board.sch]
2015-02-23 Revising silkscreen. Optimizing some traces. Updated to v10.
    [SparkFun-ESP8266-Development-Board.brd, SparkFun-ESP8266-Development-Board.sch]
2015-02-26 Removing silk labels on sensors. Changing R4 to 2k (charge at 500mA).
    [SparkFun-ESP8266-Development-Board.brd, SparkFun-ESP8266-Development-Board.sch]
2015-03-02 Adding PROD_ID to U1, S1, and Y1.
    [SparkFun-ESP8266-Development-Board.brd, SparkFun-ESP8266-Development-Board.sch]
2015-03-03 Extending border dimension out to grid.
    [SparkFun-ESP8266-Development-Board.brd]
2015-03-03 Updating dimensions measure to 2.2in.
    [SparkFun-ESP8266-Development-Board.brd]
2015-03-03 Bringing board width down to 2.18 inches.
    [SparkFun-ESP8266-Development-Board.brd]
2015-03-04 created panel v10
    [SparkFun-ESP8266-Development-Board-Panel-v10.brd]
2015-03-06 Revising TMP102, ATECC108 & TSL2561 to DNP. Moving dimensions to correct layer.
    [SparkFun-ESP8266-Development-Board.brd, SparkFun-ESP8266-Development-Board.sch]
2015-03-06 Renaming eagle files to SparkFun_ESP8266_Thing.
    [SparkFun_ESP8266_Thing.brd, SparkFun_ESP8266_Thing.sch]
2015-05-21 Fixing flash size information in schematic.
    [SparkFun_ESP8266_Thing.sch]
2015-05-22 Mapping new parts to equivalent devices in the SparkFun libraries.
    [SparkFun_ESP8266_Thing.brd, SparkFun_ESP8266_Thing.sch]
2015-09-22 Updating directory name for consistency
    [SparkFun-ESP8266-Development-Board-Panel-v10.brd]
2015-09-22 Removing checklist, adding .git files, adding license file
    [PCB checklist_V_1.0.csv, PCB checklist_V_1.0.ods]
2016-01-22 Added PDF board and schematic
2018-09-28 Remove Phant Silkscreen
    - Remove Phant and data.sparkfun.com silkscreen on .brd files in hardware and production folder.
    - Update file names
    [SparkFun-ESP8266-Development-Board-Panel-v10a.brd, SparkFun_ESP8266_Thing_V10a.brd, SparkFun_ESP8266_Thing_V10a.sch]
2019-04-22 Fix Silkscreen and Copper Width 0 Issue
    - Replace Silkscreen for SparkFun, SFE Flame, OSH logo, and RF antenna on individual board and panel with current packages from the SparkFun Eagle Library. By having a defined width for the silkscreen/copper (instead of a "0" width), the CAM job does not generate an "infinite" amount of lines for the polygon => [ [https://learn.sparkfun.com/tutorials/importing-custom-images-into-eagle/#method-1-svg-to-polygon](https://learn.sparkfun.com/tutorials/importing-custom-images-into-eagle/#method-1-svg-to-polygon) ].
    [SparkFun-ESP8266-Development-Board-Panel-v10a.brd, SparkFun_ESP8266_Thing_V10a.brd, SparkFun_ESP8266_Thing_V10a.sch]

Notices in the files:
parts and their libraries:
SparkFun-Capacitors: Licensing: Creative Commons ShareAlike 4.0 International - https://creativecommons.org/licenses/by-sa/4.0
